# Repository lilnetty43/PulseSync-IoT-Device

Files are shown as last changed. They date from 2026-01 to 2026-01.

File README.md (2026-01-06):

# PulseSync IoT Device

PulseSync IoT is a real-time heart-rate monitoring system that integrates embedded firmware, custom PCB hardware, and IoT connectivity. The system detects heartbeats using a Grove ear-clip sensor (PPG-based), synchronizes an onboard LED with each detected beat, and transmits heart-rate data wirelessly using an ESP8266 Wi-Fi module.

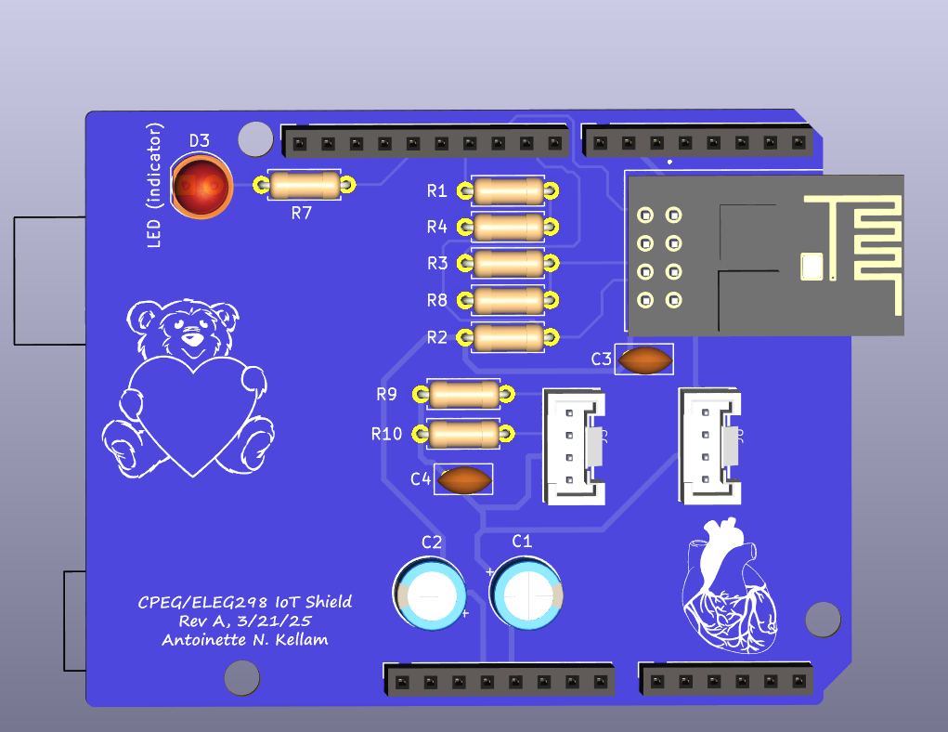
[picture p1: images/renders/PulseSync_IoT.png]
PulseSync IoT PCB – 3D Render


*KiCad-generated 3D render of the finalized PCB layout for visual reference and board geometry.*

---

## Project Overview

- **Heart-rate sensing:** Grove ear-clip sensor using photoplethysmography (PPG)
- **Microcontroller:** Arduino Uno
- **Wireless communication:** ESP-01S (ESP8266)
- **Visual feedback:** Onboard LED synchronized to detected heartbeats
- **PCB design:** Custom Arduino Uno–compatible shield designed in KiCad

This project was developed as part of **CPEG/ELEG298** and demonstrates my foundational skills in embedded systems, PCB design, sensor interfacing, and IoT-based data transmission.

---

## Repository Structure

```text
PulseSync-IoT-Device/
├── README.md              # Main project overview
├── LICENSE
├── firmware/              # Embedded Arduino (C/C++) firmware
│   └── README.md
├── hardware/              # PCB design and fabrication files
│   ├── README.md
│   ├── kicad/             # KiCad schematic & PCB source (if available)
│   ├── fabrication/       # Manufacturing-ready files
│   │   ├── gerbers/       # Gerber layer files
│   │   └── drill/         # Excellon drill files and drill maps
│   └── outputs/           # BOM, schematic PDFs, rendered PCB views
├── images/                # PCB visuals and inspection images
│   ├── README.md
│   ├── renders/           # KiCad 3D board renders
│   │   ├── PulseSync_IoT_3D_Top.png
│   │   └── PulseSync_IoT_3D_Bottom.png
│   ├── routing/           # PCB routing views
│   │   └── PulseSync_IoT_Routed_Top.png
│   ├── TOP_placement_BOM_overlay.png
│   └── BOTTOM_placement_BOM_overlay.png
└── docs/                  # Final report and presentation slides
    ├── README.md
    ├── report/
    └── slides/

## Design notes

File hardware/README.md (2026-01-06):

# PulseSync IoT – Hardware Design

This directory contains the complete hardware design artifacts for the PulseSync IoT heart-rate monitoring system, developed using KiCad.

---

## Design Overview

- Interfaces a Grove ear-clip heart-rate sensor with an Arduino Uno
- Integrates an ESP-01S (ESP8266) Wi-Fi module for wireless data transmission
- Includes onboard LED indication synchronized to detected heartbeats
- Implemented as a two-layer PCB with top-layer signal routing and a bottom-layer ground fill
- A routed PCB layout view is provided in the `images/` directory for reference

---
## Schematic Overview

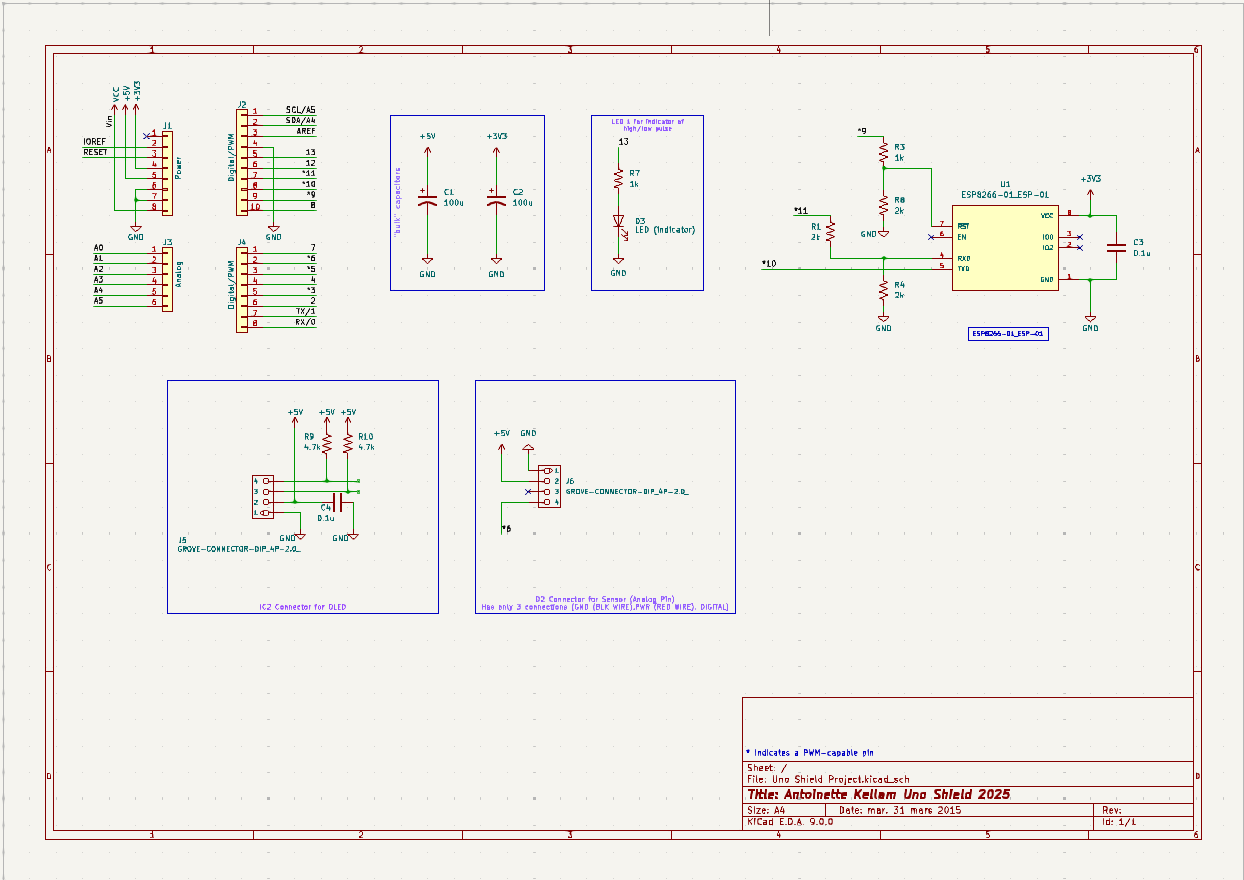
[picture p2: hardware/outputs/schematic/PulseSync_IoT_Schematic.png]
PulseSync IoT Schematic


*Exported schematic view showing sensor interface, ESP-01S integration, power regulation, and I/O mapping.*

## Design Tools

- **EDA Tool:** KiCad  
- **Design Stages:** Schematic capture, I/O mapping, power regulation, PCB layout, and design rule verification

---

## Directory Structure

### `kicad/`
Intended to contain editable KiCad project source files, including schematics, PCB layout files, custom symbols, footprints, and 3D models used in the design.

#### Project Archival Note
The original KiCad project source files (`.kicad_sch` and `.kicad_pcb`) were not preserved during early fabrication submissions. As a result, the editable schematic and PCB source files are no longer available.

The finalized design is instead represented through the manufacturing-ready outputs (Gerber and drill files) and human-readable documentation provided elsewhere in this directory.
Exported schematic PDFs are included in the `outputs/` directory to preserve circuit-level design intent.

---

### `fabrication/`
Manufacturing outputs generated from KiCad, including:

- Gerber layer files
- Excellon drill files and drill maps

These files represent the finalized, fabrication-ready version of the PCB and were used for board manufacturing.

---

### `outputs/`
Human-readable design documentation, including:

- Exported schematic PDFs
- Bill of Materials (BOM)
- Rendered PCB views and visual references

These files preserve design intent and enable review, verification, and documentation of the hardware design despite the absence of editable source files.

---

## Notes

- Design Rule Checking (DRC) was performed to verify layout correctness prior to fabrication
- Fabrication files are provided for reference and demonstration of PCB manufacturing readiness

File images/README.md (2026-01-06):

---
## PCB Layout and Component Placement Files

### Top Layer – Component Placement (with BOM Overlay)
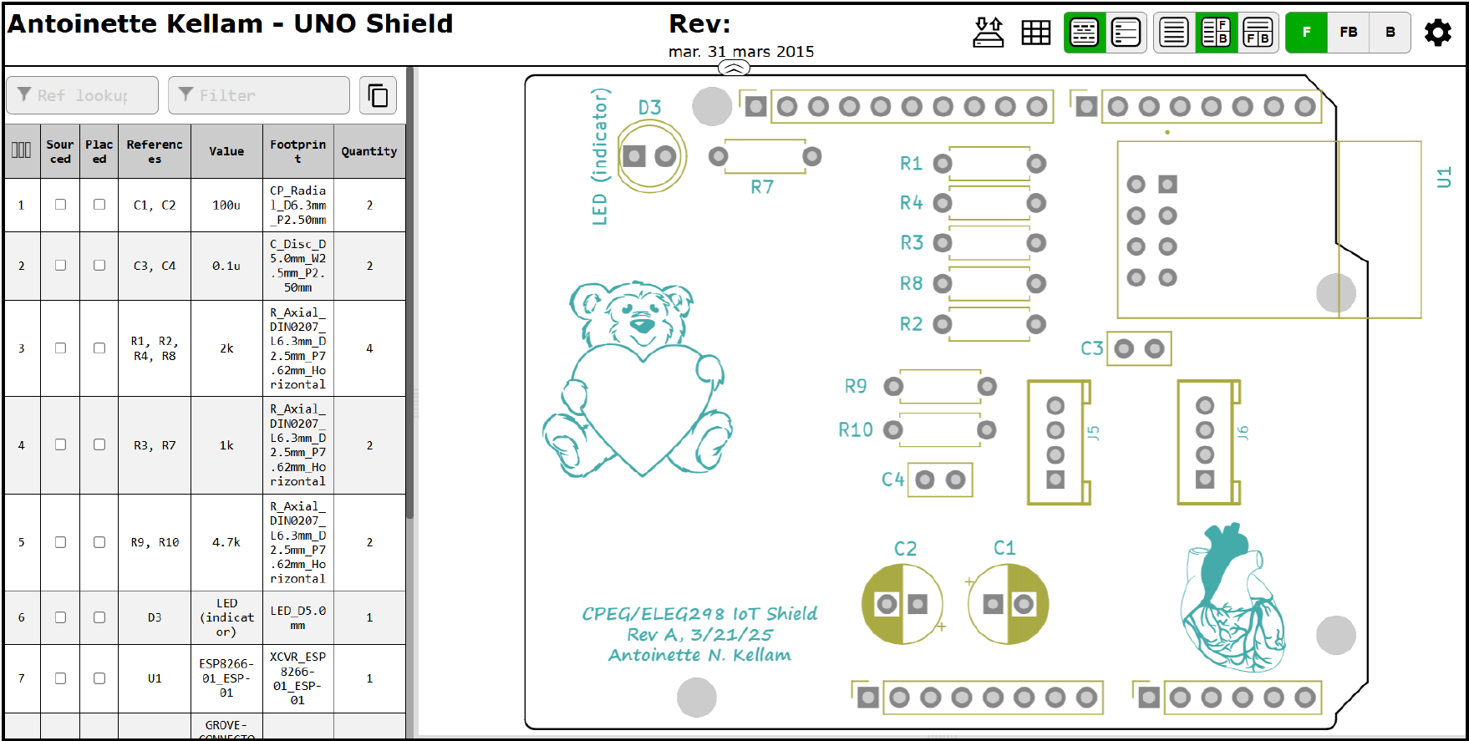
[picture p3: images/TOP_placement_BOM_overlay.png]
Top Placement + BOM


### Bottom Layer – Component Placement (with BOM Overlay)
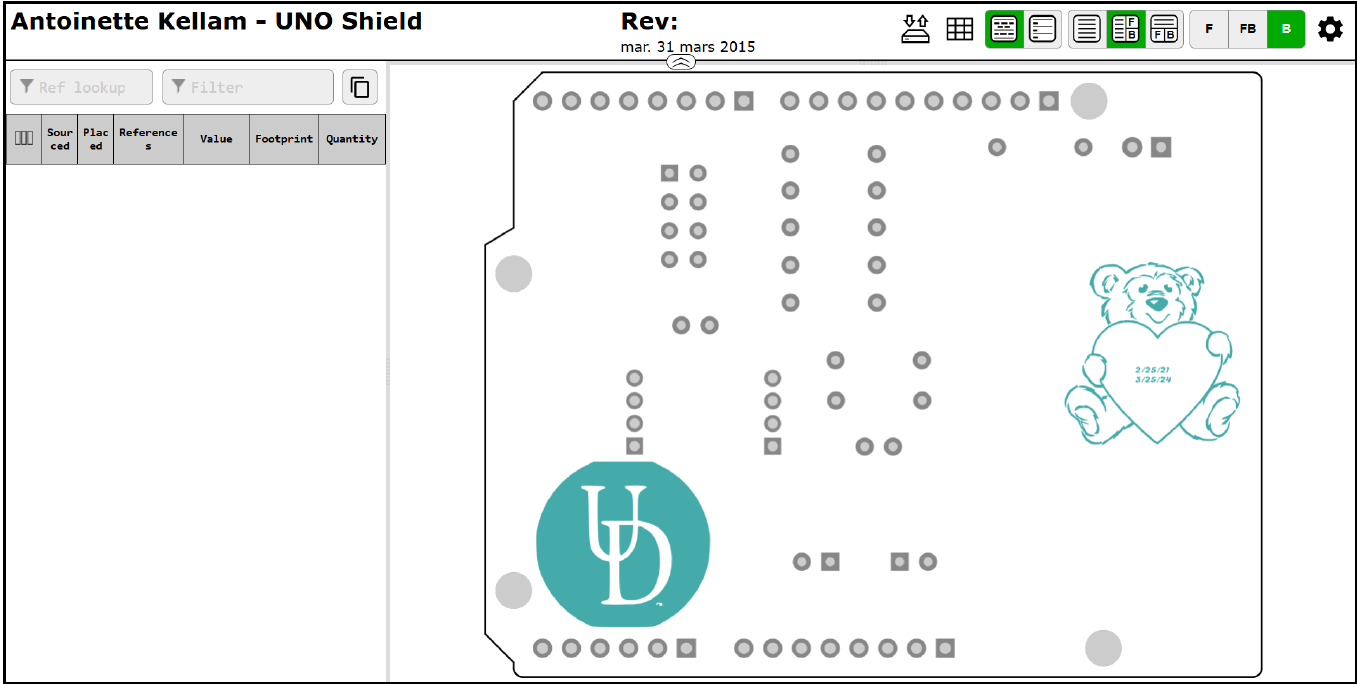
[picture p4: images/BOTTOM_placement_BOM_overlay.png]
Bottom Placement + BOM


## PCB Routing View

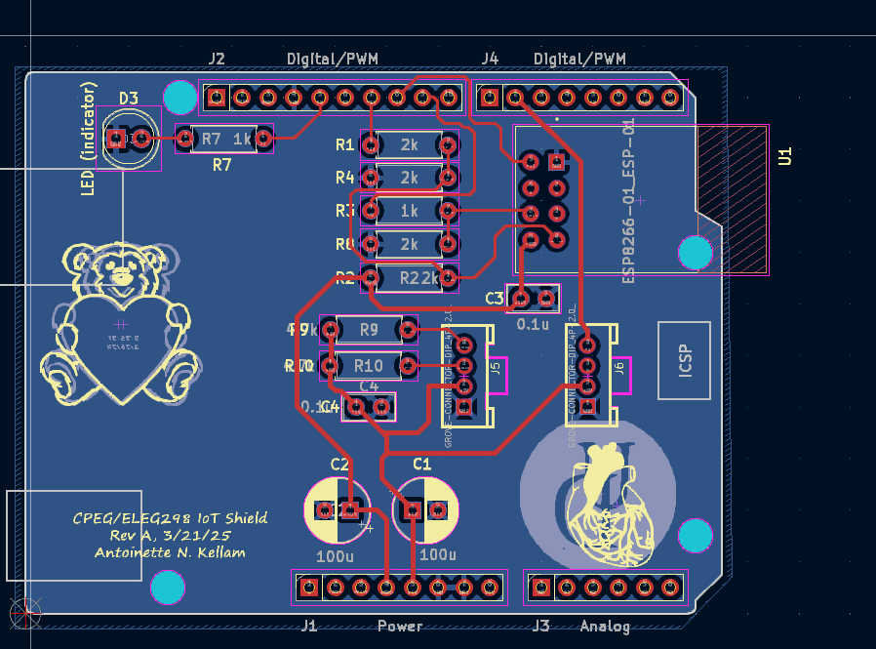
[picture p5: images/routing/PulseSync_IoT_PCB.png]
Top Layer Routing


This view highlights top-layer copper routing, signal paths, and component connectivity for the PulseSync IoT PCB.

## KiCad 3D Renders

### Top View
3D Top View

### Bottom View
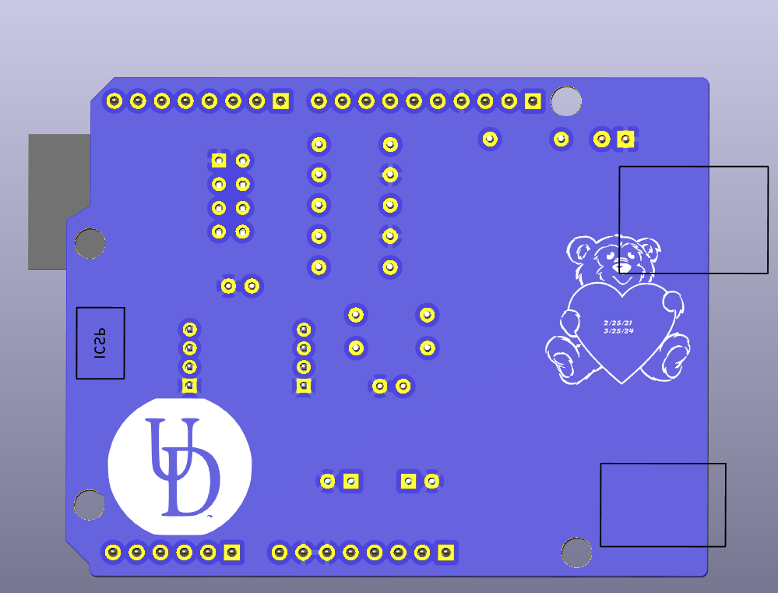
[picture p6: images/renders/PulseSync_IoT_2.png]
3D Bottom View


These renders were generated using KiCad’s 3D Viewer and are provided for visual reference of component placement and board geometry.

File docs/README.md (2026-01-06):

---
# Project Documentation

This directory contains the final documentation for the **PulseSync IoT** project, including the written report and presentation materials submitted for CPEG/ELEG298.

## Contents

### Final Report
- `report/PulseSync_IoT_Final_Report.pdf`  
  Comprehensive technical report covering system design, hardware implementation, firmware development, testing, and results.

### Presentation Slides
- `slides/PulseSync_IoT_Final_Presentation.pdf`  
  Final project presentation summarizing objectives, design approach, challenges, and outcomes.

## Related Directories
- Hardware design files are located in `/hardware`
- Firmware source code is located in `/firmware`
- PCB images and placement diagrams are located in `/images`

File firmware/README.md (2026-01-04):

---
# PulseSync IoT – Firmware

Embedded C/C++ firmware for the PulseSync IoT heart-rate monitoring device.

## Hardware Platform
- **Microcontroller:** Arduino Uno  
- **Wi-Fi Module:** ESP-01S  
  - Communication via SoftwareSerial on D10 (TX) / D11 (RX)

## I/O Configuration
- **Heart Rate Sensor:** Grove Ear-Clip Sensor  
  - Input Pin: D6 (configured with `INPUT_PULLUP`)
- **Status LED:**  
  - Output Pin: D13  
  - Flashes on each detected heartbeat

## Functionality
- Performs real-time heart-rate detection using PPG-based pulse sensing  
- Calculates instantaneous BPM based on beat-to-beat timing  
- Publishes BPM data to **Adafruit IO**  
  - Feed name: `HeartRate`
- Maintains non-blocking sensor polling and LED synchronization during Wi-Fi transmissions

## Notes
- The ESP-01S uses a **project-specific command interface** for Wi-Fi and Adafruit IO communication  
- Credentials (Wi-Fi SSID, passwords, API keys) are intentionally omitted and must be supplied by the user

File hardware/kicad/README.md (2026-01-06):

---

###
This directory is intended to contain KiCad schematic and PCB source files for the PulseSync IoT hardware design.

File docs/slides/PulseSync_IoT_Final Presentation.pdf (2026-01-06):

# PulseSync IoT: Real-Time Heart-Rate Monitor w/LED Synchronization

Designed/Tested by Antoinette Kellam - CPEG298

# Schematic & Circuit Design

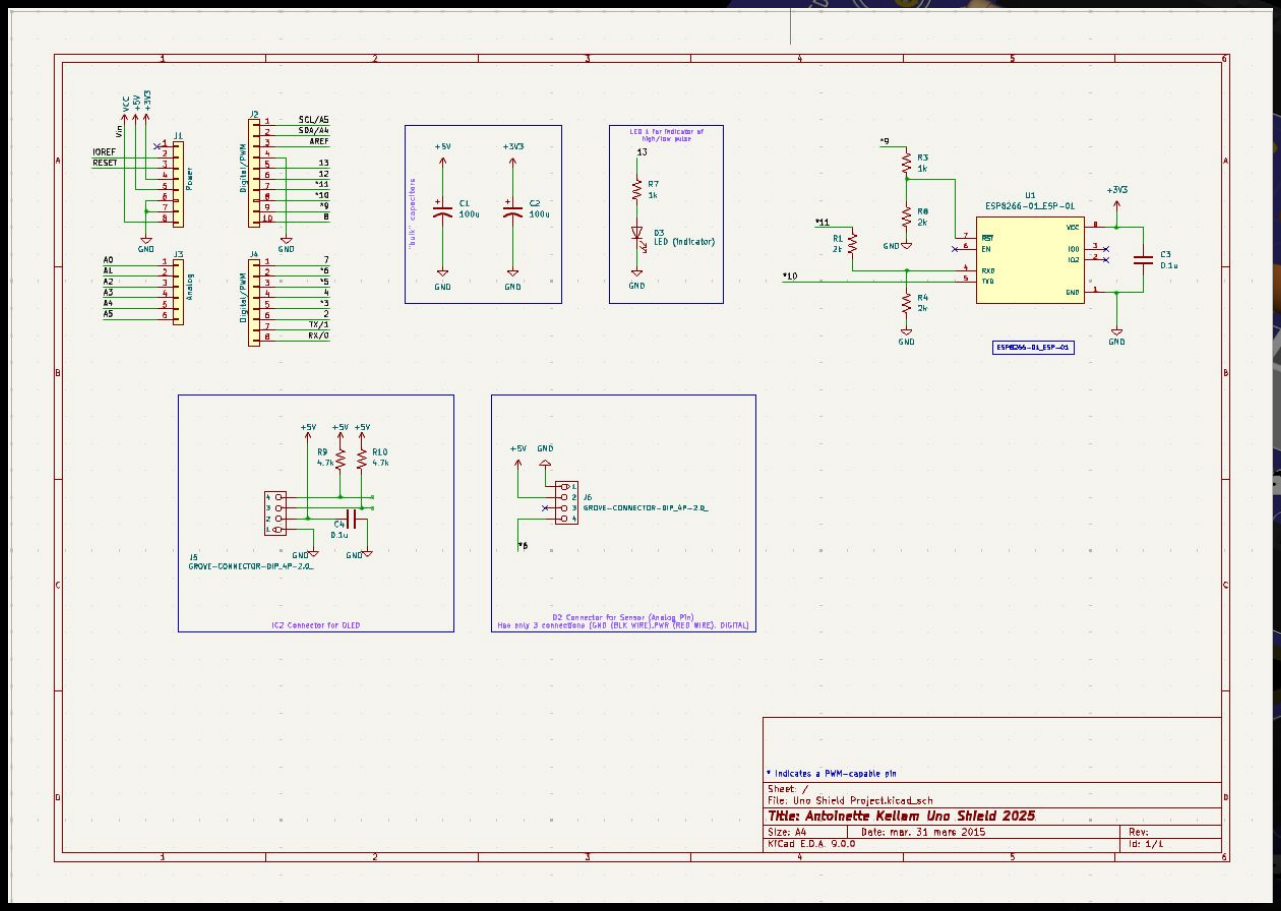
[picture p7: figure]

The KiCad schematic (.kicad_sch) of my IoT Heart Rate device is shown. The Arduino UNO connections, like power and I/O headers, are shown.

In the top-center, I have 2 bulk capacitors (100uF on 5V and +3V3 rails).

The upper-far-right displays the ESP8266-01 WiFi module with its 3.3V bypass capacitors and resistors that are in connections to the Arduino Uno 5V UART and EN lines.

The lower-left houses the Grove I2C port connector for an OLED screen that could be used to display the current bpm (*this was not functioning properly).

Centered below my “bulk capacitors” is the Grove Senor port that houses the main sensor used in this project. This was a 3-wire connector for the Grove-Ear-Clip Heart Rate Sensor: GND, PWR, and Digital Pin that supplies 5V and GND.

# PCB Design

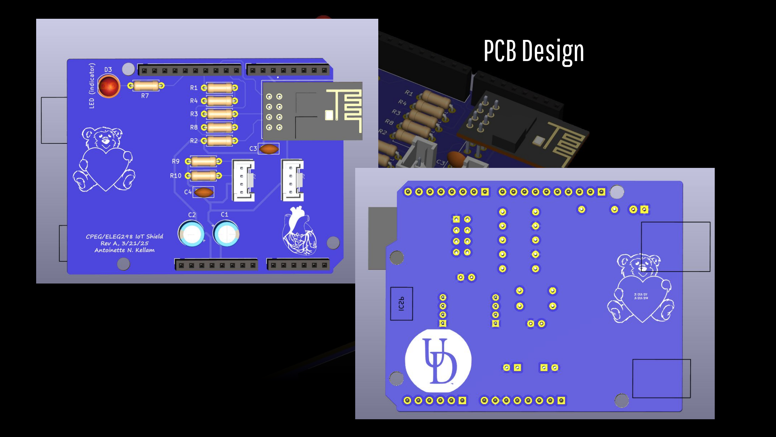
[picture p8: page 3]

# BOM DIAGRAM

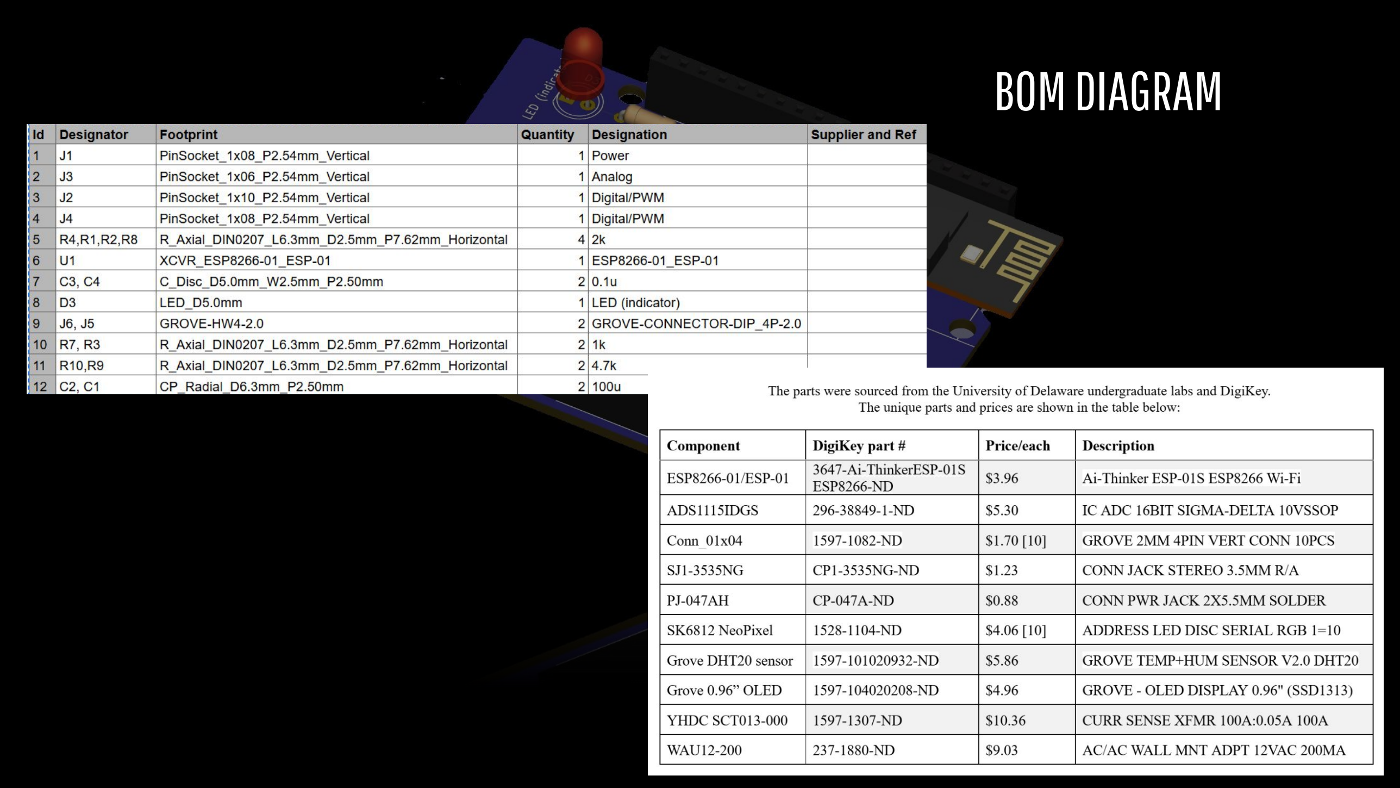
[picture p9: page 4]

# ARDUINO CODE HIGHLIGHTS

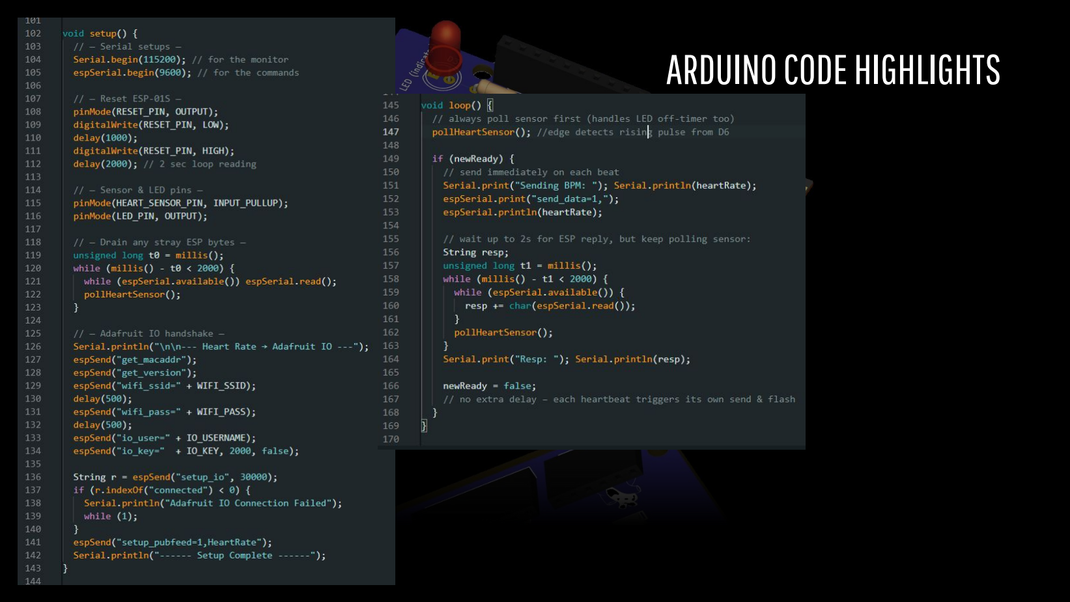
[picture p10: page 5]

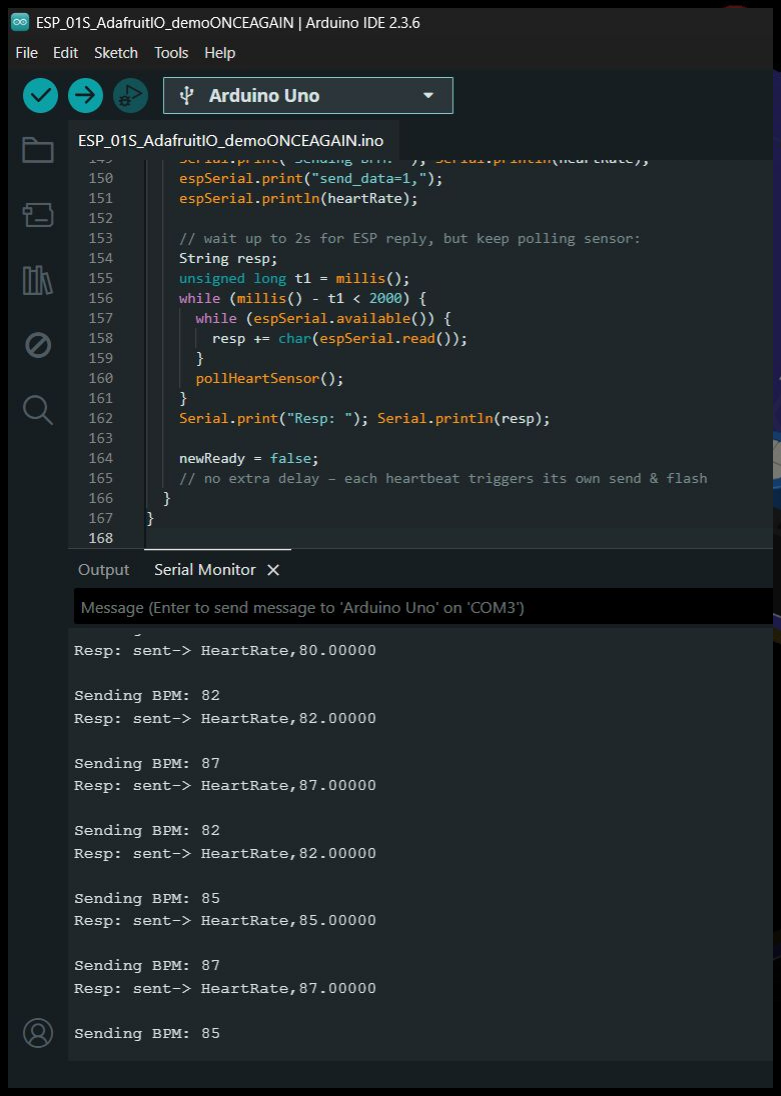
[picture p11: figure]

# SERIAL MONITOR/PLOTTER

# ADAFRUIT DASHBOARD/FEED

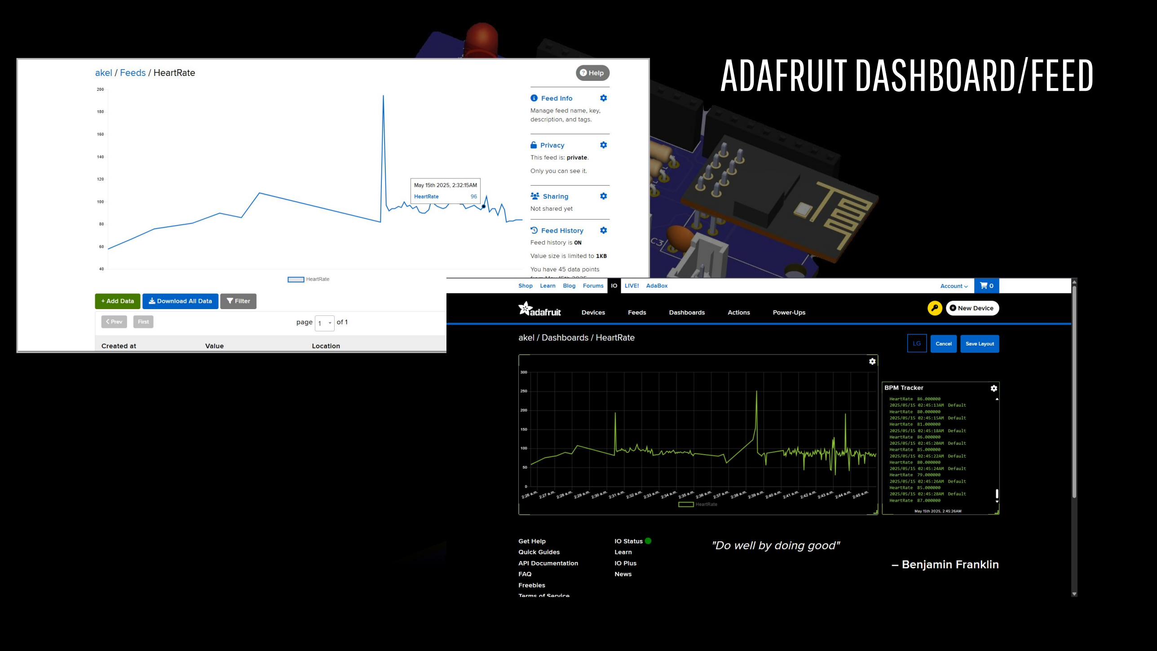
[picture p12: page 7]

# SUPPLEMENTARY VIDEOS

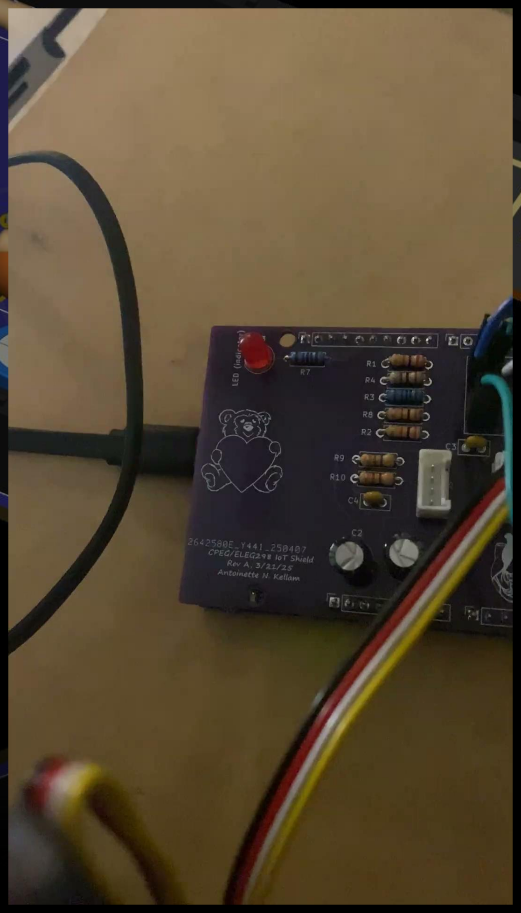
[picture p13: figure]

HEART RATE SENSOR (ALONE WORKING) | COMPLETE PROJECT WORKING (SENDING DATA VIA WIFI MODULE)

# DEMO!

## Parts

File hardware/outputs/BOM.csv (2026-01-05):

PulseSync IoT – Costed Bill of Materials
Component | DigiKey Part Number | Price Each (USD) | Description | Notes
ESP8266-01 / ESP-01S | 3647-Ai-ThinkerESP-01S ESP8266-ND | 3.96 | Ai-Thinker ESP-01S ESP8266 Wi-Fi Module
ADS1115IDGS | 296-38849-1-ND | 5.30 | 16-bit Sigma-Delta ADC IC (VSSOP)
Grove Connector 4-pin (2mm) | 1597-1082-ND | 1.70 | Grove 2mm 4-pin Vertical Connector | Price shown per 10-pack
SJ1-3535NG | CP1-3535NG-ND | 1.23 | 3.5mm Stereo Audio Jack (Right Angle)
PJ-047AH | CP-047A-ND | 0.88 | DC Power Jack 2.0x5.5mm Through-Hole
SK6812 NeoPixel | 1528-1104-ND | 4.06 | Addressable RGB LED Disc | Price shown per 10-pack
Grove DHT20 Sensor | 1597-101020932-ND | 5.86 | Grove Temperature & Humidity Sensor v2.0 (DHT20)
Grove 0.96in OLED | 1597-104020208-ND | 4.96 | Grove OLED Display 0.96in (SSD1313)
YHDC SCT013-000 | 1597-1307-ND | 10.36 | Current Sense Transformer 100A:0.05A
WAU12-200 | 237-1880-ND | 9.03 | 12VAC 200mA Wall-Mount Power Adapter

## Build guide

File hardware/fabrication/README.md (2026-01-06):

---
Fabrication outputs for the PulseSync IoT UNO shield PCB.

Includes Gerber and drill files suitable for PCB manufacturing.

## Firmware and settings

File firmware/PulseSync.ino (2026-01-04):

/***************************************************************************
 Antoinette Kellam - CPEG298 - Spring 2025

    ESP-01S + Grove Ear-Clip Heart Sensor on D6 → Adafruit IO 
  • SoftwareSerial on D10/D11 for ESP-01
  • Poll D6 for beats, flash D13 at each beat
  • Publish instantaneous BPM immediately (and keep polling during send)


 NOTE:
 The ESP-01S in this project uses a custom command interface / firmware
 wrapper (e.g., wifi_ssid=, setup_io, send_data) rather than stock ESP AT
 commands. These commands are specific to the ESP-01S setup used in this
 project and are not part of the default Espressif AT firmware.
***************************************************************************/
#include <Arduino.h>
#include <SoftwareSerial.h>  // Allows us to use two GPIO pins for a second UART

// ——— Pin definitions ———
#define RESET_PIN         9   // ESP-01S CH_PD/RESET
#define UART_RX_PIN      11   // ESP-01 TX → D11
#define UART_TX_PIN      10   // ESP-01 RX ← D10
#define HEART_SENSOR_PIN  6   // Grove sensor → D6
#define LED_PIN          13   // Indicator LED net “13” in your schematic

// ——— SoftwareSerial for ESP-01 ———
SoftwareSerial espSerial(UART_RX_PIN, UART_TX_PIN);

// ——— Adafruit IO credentials ———
const String IO_USERNAME = "YOUR_ADAFRUIT_IO_USERNAME";
const String IO_KEY      = "YOUR_ADAFRUIT_IO_KEY";
const String WIFI_SSID   = "YOUR_WIFI_SSID";
const String WIFI_PASS   = "YOUR_WIFI_PASSWORD";

// ——— Heart-beat detection globals ———
unsigned long lastBeatTime = 0;      // timestamp of last beat
unsigned int  heartRate    = 0;      // computed BPM
bool          newReady     = false;  // flag: a new BPM is ready

// ——— LED flash timing (non-blocking) ———
unsigned long ledOnTime       = 0;
const unsigned long ledFlashDuration = 50; // ms

// ——— For edge-detecting the sensor pin ———
bool lastSensorState = LOW;

// ——— Helper: send AT-style cmd & collect response ———
String espSend(const String &cmd, int timeout=2000, bool dbg=true) {
  String resp;
  Serial.print("> "); Serial.println(cmd);
  espSerial.println(cmd);
  unsigned long start = millis();
  while (millis() - start < timeout) {
    while (espSerial.available()) {
      resp += char(espSerial.read());
    }
    // keep heart polling alive while waiting:
    // (so LED still flashes on beats during long publishes)
    bool now = digitalRead(HEART_SENSOR_PIN);
    if (now && !lastSensorState) {
      unsigned long t = millis();
      unsigned long delta = t - lastBeatTime;
      lastBeatTime = t;
      if (delta < 2000) {
        heartRate = 60000UL / delta;
        newReady  = true;  // allow immediate send back in loop
      }
      // schedule LED flash
      digitalWrite(LED_PIN, HIGH);
      ledOnTime = millis();
    }
    lastSensorState = now;
  }
  resp.trim();
  if (dbg) {
    Serial.print("Resp: "); Serial.println(resp);
  }
  return resp;
}

// ——— Poll the heart sensor & LED off-timer ———
void pollHeartSensor() {
  bool now = digitalRead(HEART_SENSOR_PIN);

  // on rising edge → record a beat
  if (now && !lastSensorState) {
    unsigned long t = millis();
    unsigned long delta = t - lastBeatTime;
    lastBeatTime = t;

    if (delta < 2000) {
      heartRate = 60000UL / delta;  // instantaneous BPM
      newReady  = true;
    }

    // schedule LED flash
    digitalWrite(LED_PIN, HIGH);
    ledOnTime = millis();
  }
  lastSensorState = now;

  // turn LED off once its flash-duration is up
  if (ledOnTime && (millis() - ledOnTime >= ledFlashDuration)) {
    digitalWrite(LED_PIN, LOW);
    ledOnTime = 0;
  }
}

void setup() {
  // — Serial setups —
  Serial.begin(115200); // for the monitor
  espSerial.begin(9600); // for the commands

  // — Reset ESP-01S —
  pinMode(RESET_PIN, OUTPUT);
  digitalWrite(RESET_PIN, LOW);
  delay(1000);
  digitalWrite(RESET_PIN, HIGH);
  delay(2000); // 2 sec loop reading

  // — Sensor & LED pins —
  pinMode(HEART_SENSOR_PIN, INPUT_PULLUP);
  pinMode(LED_PIN, OUTPUT);

  // — Drain any stray ESP bytes —
  unsigned long t0 = millis();
  while (millis() - t0 < 2000) {
    while (espSerial.available()) espSerial.read();
    pollHeartSensor();
  }

  // — Adafruit IO handshake —
  Serial.println("\n\n--- Heart Rate → Adafruit IO ---");
  espSend("get_macaddr");
  espSend("get_version");
  espSend("wifi_ssid=" + WIFI_SSID);
  delay(500);
  espSend("wifi_pass=" + WIFI_PASS);
  delay(500);
  espSend("io_user=" + IO_USERNAME);
  espSend("io_key="  + IO_KEY, 2000, false);

  String r = espSend("setup_io", 30000);
  if (r.indexOf("connected") < 0) {
    Serial.println("Adafruit IO Connection Failed");
    while (1);
  }
  espSend("setup_pubfeed=1,HeartRate");
  Serial.println("------ Setup Complete ------");
}

void loop() {
  // always poll sensor first (handles LED off-timer too)
  pollHeartSensor(); //edge detects rising pulse from D6

  if (newReady) {
    // send immediately on each beat
    Serial.print("Sending BPM: "); Serial.println(heartRate);
    espSerial.print("send_data=1,");
    espSerial.println(heartRate);

    // wait up to 2s for ESP reply, but keep polling sensor:
    String resp;
    unsigned long t1 = millis();
    while (millis() - t1 < 2000) {
      while (espSerial.available()) {
        resp += char(espSerial.read());
      }
      pollHeartSensor();
    }
    Serial.print("Resp: "); Serial.println(resp);

    newReady = false;
    // no extra delay – each heartbeat triggers its own send & flash
  }
}

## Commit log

2026-01-04 Add README for PulseSync IoT device firmware
2026-01-04 Update README with device information and features
    Added detailed information about the hardware and functionality of the PulseSync IoT device.
2026-01-04 Enhance README with detailed firmware information
    here i expand the README to include hardware platform, I/O configuration, functionality, and notes for the PulseSync IoT device.
2026-01-05 Update BOM.csv with new component entries
    Added components with details to the BOM.
    [BOM.csv]
2026-01-05 Add header row to BOM.csv
    [BOM.csv]
2026-01-05 Update BOM.csv with header and format changes
    Added header and updated BOM format.
    [BOM.csv]
2026-01-05 Update README with PCB layout and component placement
    Added PCB layout and component placement details to README.
2026-01-06 Rename BOTTOM placement + BOM overlay.png to BOTTOM_placement_BOM_overlay
2026-01-06 Rename TOP placement + BOM overlay.png to TOP_placement_BOM_overlay
2026-01-06 Revise PCB layout README with BOM overlays
    Updated PCB layout documentation to include BOM overlays for top and bottom layer placements.
2026-01-06 Create kicad
2026-01-06 Update README with KiCad design information
    Add description for KiCad design files.
2026-01-06 Update README.md for KiCad design files
2026-01-06 Create gerbers
2026-01-06 Add project archival note to README
    Added archival note regarding missing original KiCad project files.
2026-01-06 Update README.md to clarify KiCad files purpose
    Removed archival note about missing original KiCad files.
2026-01-06 Add README with project documentation details
    Added project documentation including final report and presentation materials.
2026-01-06 Revise README for PulseSync IoT Device
    Updated project description, added overview and repository structure.
2026-01-06 Add KiCad 3D renders to README
    Added 3D renders of the PulseSync IoT board for visual reference.
2026-01-06 Update PCB image in README with 3D render
2026-01-06 Add PCB Routing View section to README
    Added PCB routing view section with an image and description.
2026-01-06 Update README with PCB routing details
    Added information about PCB routing and layout view.
2026-01-06 Simplify README description for hardware design
    Removed details about the custom Arduino Uno-compatible shield from the README.
2026-01-06 Add schematic overview to README
    Added schematic overview section with image and description.
2026-01-06 Fix schematic image path in README
    Updated schematic image path in README.
2026-01-06 Fix image path in README for schematic overview
    Updated image path for the PulseSync IoT schematic.
